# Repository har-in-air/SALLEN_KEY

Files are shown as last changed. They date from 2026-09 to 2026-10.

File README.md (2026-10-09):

# Stereo 2-way 2nd order active crossover (Sallen Key)

Crossover frequency Fc = 1/( 2 * pi * R * C)

In the schematic, R = 5.6K, C = 100nF, so Fc ~= 284 Hz.

## Top
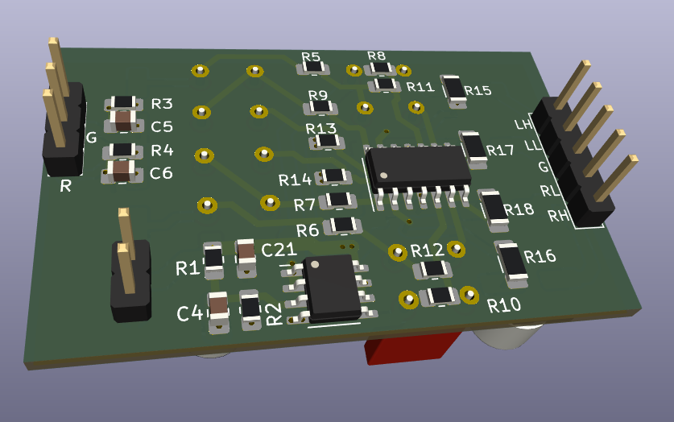
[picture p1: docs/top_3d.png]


## Bottom
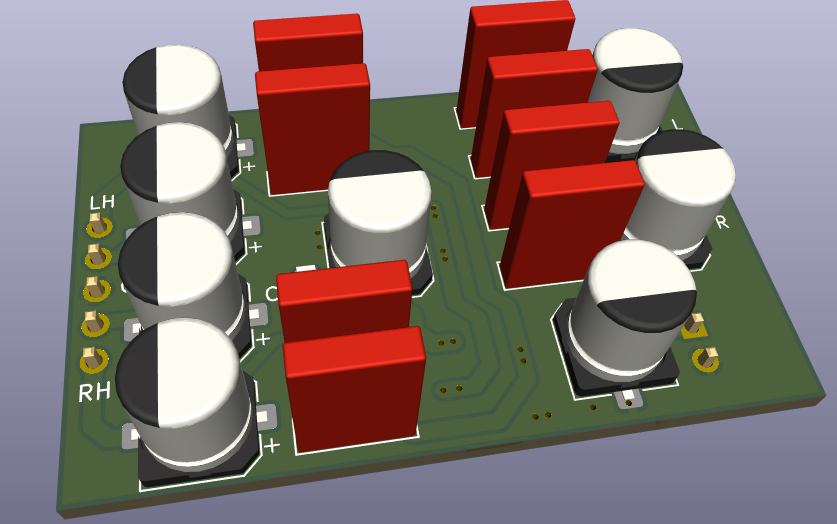
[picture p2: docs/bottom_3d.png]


## 2.1 option
For a 2.1 amplifier filter configuration:  

* Do not populate R12, R18, C14, C16, C19
* Populate R6
* Populate R10 so that the unused opamp U2B +input is not floating.
* Solder a jumper wire across x1, x2 points in the schematic
* The summed low-pass filter output is on LLo output

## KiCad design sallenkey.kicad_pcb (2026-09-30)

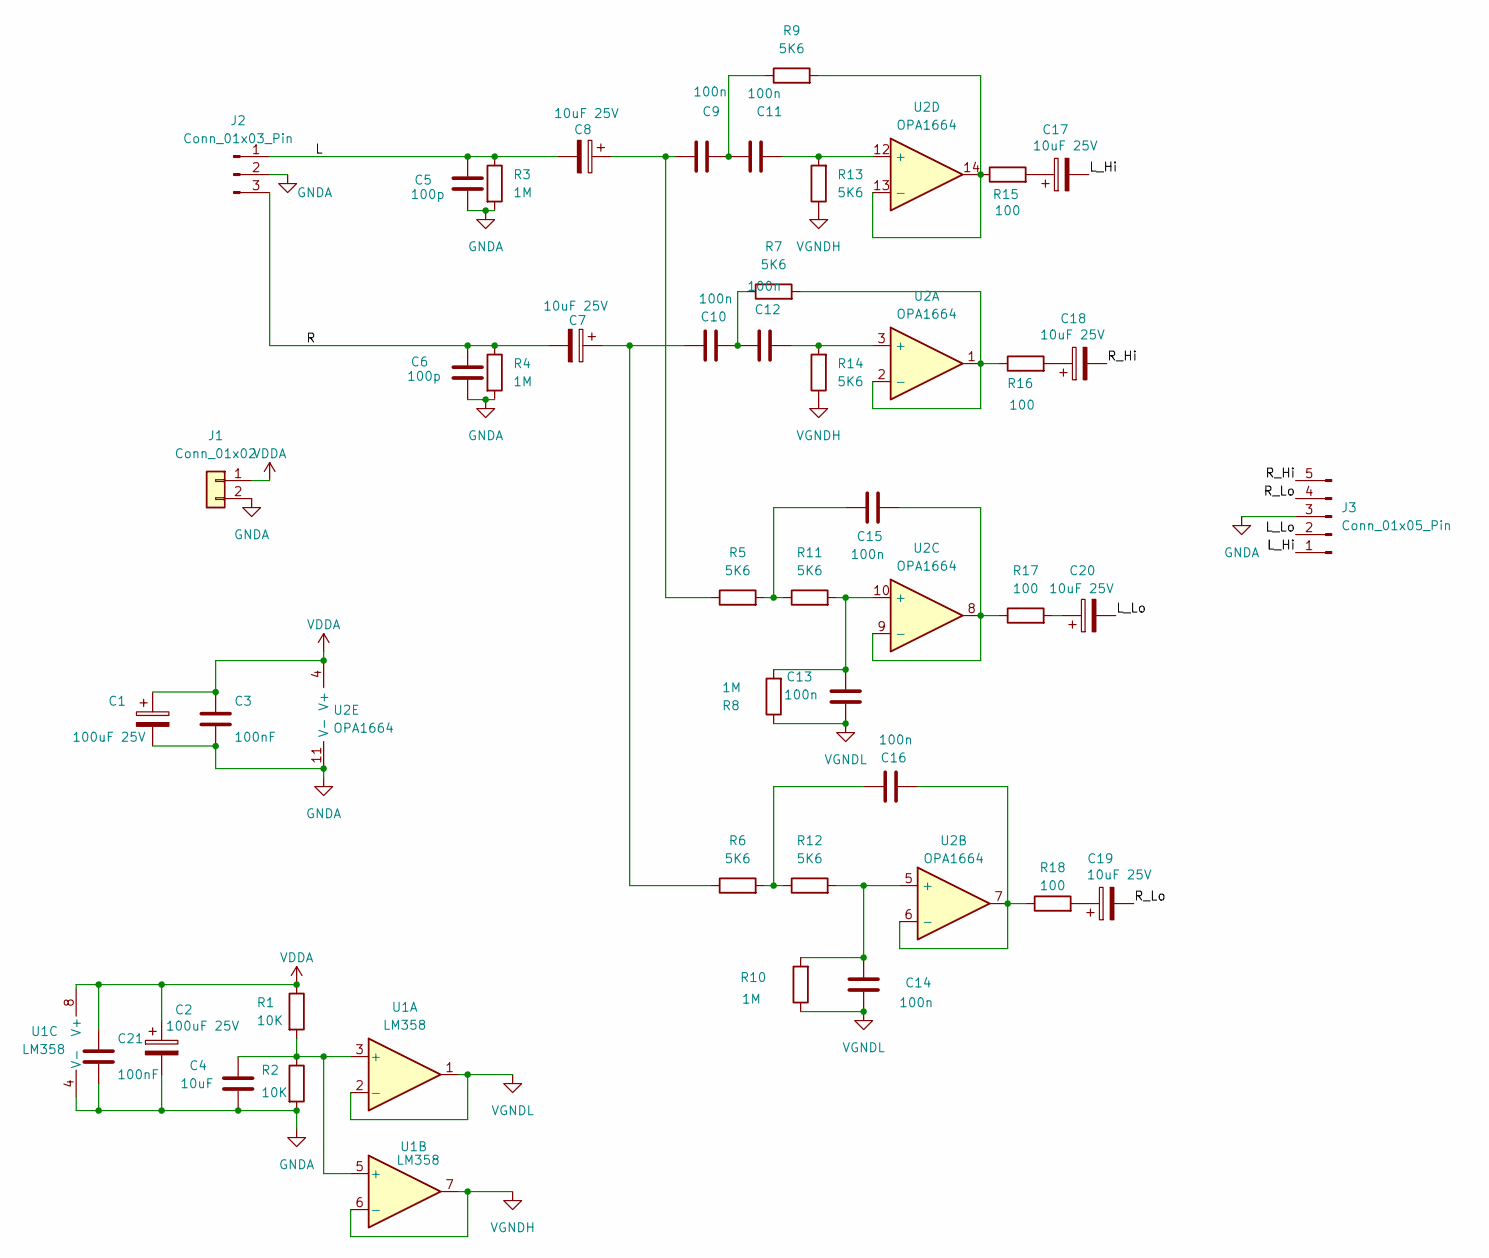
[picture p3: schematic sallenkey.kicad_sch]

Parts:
C1, C2: 100uF 25V; CP_Elec_6.3x7.7
C3, C21: 100nF; C_0805_2012Metric_Pad1.18x1.45mm_HandSolder
C4: 10uF; C_0805_2012Metric_Pad1.18x1.45mm_HandSolder
C5, C6: 100p; C_0805_2012Metric_Pad1.18x1.45mm_HandSolder
C7, C8, C17, C18, C19, C20: 10uF 25V; CP_Elec_6.3x7.7
C9, C10, C11, C12, C13, C14, C15, C16: 100n; C_Rect_L7.0mm_W2.0mm_P5.00mm
J1: Conn_01x02; PinHeader_1x02_P2.54mm_Vertical
J2: Conn_01x03_Pin; PinHeader_1x03_P2.54mm_Vertical
J3: Conn_01x05_Pin; PinHeader_1x05_P2.54mm_Vertical
R1, R2: 10K; R_0805_2012Metric_Pad1.20x1.40mm_HandSolder
R3, R4, R8, R10: 1M; R_0805_2012Metric_Pad1.20x1.40mm_HandSolder
R5, R6, R7, R9, R11, R12, R13, R14: 5K6; R_0805_2012Metric_Pad1.20x1.40mm_HandSolder
R15, R16, R17, R18: 100; R_1206_3216Metric_Pad1.30x1.75mm_HandSolder
U1: LM358; SOIC-8_3.9x4.9mm_P1.27mm
U2: OPA1664; SOIC-14_3.9x8.7mm_P1.27mm

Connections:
/L: C5.1, C8.2, J2.1, R3.1
/L_Hi: C17.2, J3.1
/L_Lo: C20.2, J3.2
/R: C6.1, C7.2, J2.3, R4.1
/R_Hi: C18.2, J3.5
/R_Lo: C19.2, J3.4
GNDA: C1.2, C2.2, C3.2, C4.2, C5.2, C6.2, C21.2, J1.2, J2.2, J3.3, R2.2, R3.2, R4.2, U1.4 (V-), U2.11 (V-)
unnamed: C8.1, C9.2, R5.1
unnamed: C10.1, C12.2, R7.1
unnamed: C7.1, C10.2, R6.1
unnamed: C9.1, C11.2, R9.1
unnamed: C15.1, R5.2, R11.1
unnamed: C16.2, R6.2, R12.1
unnamed: C17.1, R15.2
unnamed: C18.1, R16.2
unnamed: C19.1, R18.2
unnamed: C20.1, R17.2
unnamed: C4.1, R1.2, R2.1, U1.3 (+), U1.5 (+)
unnamed: C12.1, R14.2, U2.3 (+)
unnamed: R7.2, R16.1, U2.1, U2.2 (-)
unnamed: C14.2, R10.2, R12.2, U2.5 (+)
unnamed: C16.1, R18.1, U2.6 (-), U2.7
unnamed: C13.2, R8.2, R11.2, U2.10 (+)
unnamed: C15.2, R17.1, U2.8, U2.9 (-)
unnamed: C11.1, R13.2, U2.12 (+)
unnamed: R9.2, R15.1, U2.13 (-), U2.14
VDDA: C1.1, C2.1, C3.1, C21.1, J1.1, R1.1, U1.8 (V+), U2.4 (V+)
VGNDH: R13.1, R14.1, U1.6 (-), U1.7
VGNDL: C13.1, C14.1, R8.1, R10.1, U1.1, U1.2 (-)

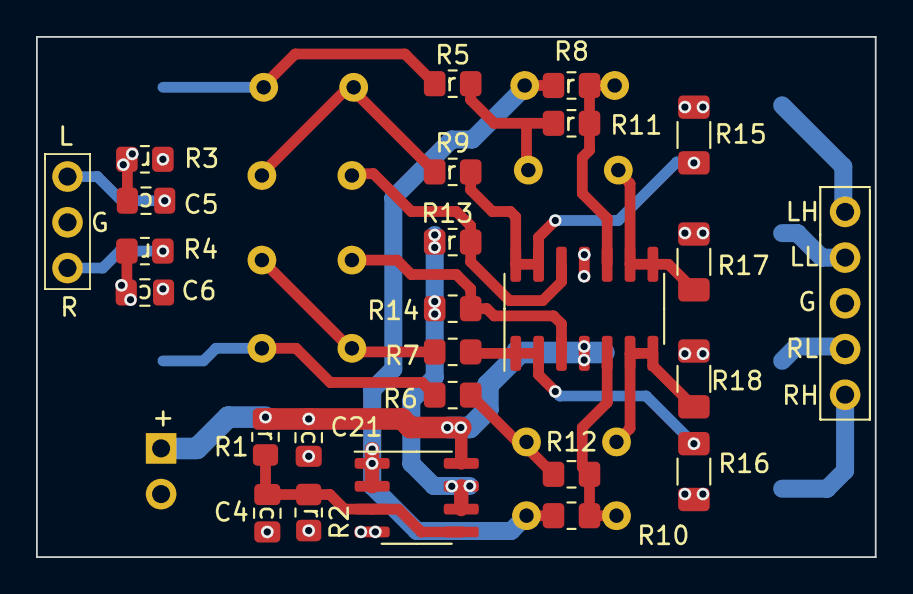
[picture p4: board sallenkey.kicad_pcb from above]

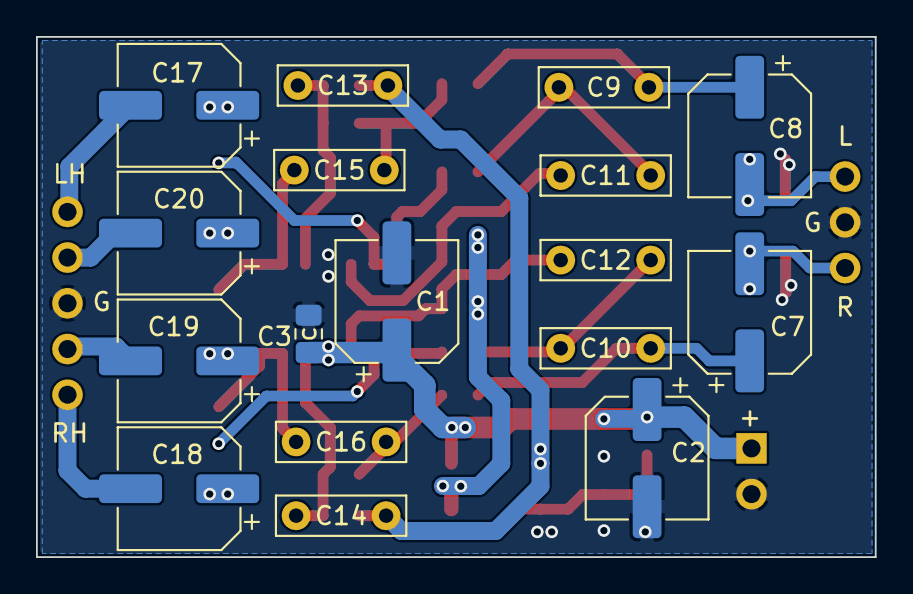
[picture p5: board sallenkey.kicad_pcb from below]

Board: 2 copper layers, 46.6 x 28.9 mm, 44 parts (17 on the bottom side), 29 nets.
